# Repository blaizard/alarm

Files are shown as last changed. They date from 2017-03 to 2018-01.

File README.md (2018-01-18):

# Aube

Beautiful. Simple. Smart.

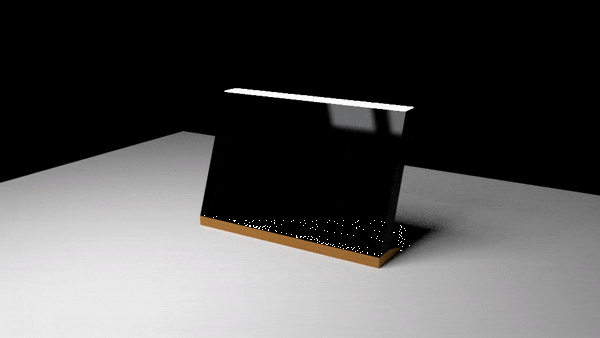
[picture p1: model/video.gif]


Aube is a smart alarm clock. It will guide you from the time you touch your bed until you wake up and is here make it a pleasant experience.
Aube is 3 major ideas: a design, a light and a smart device. 

## How to build Aube

The prototype is based on a Raspberry Pi 3 with the official 7 inches touch screen.
To fully build Aube, you will need a 3d printer, electronic circuit knowledges and some time!

The source contains various directories:
- **casing**: Contains the 3d models to be printed in order to build the skeleton of Aube
- **fw**: The firmware written in C to be compiled and loaded to a Microchip SAMD21 Microcontroller
- **schematics**: The electronics to handle the LED lighting with proximity sensor and the other sensors
- **sw**: The GUI of the alarm clock, written in Vanilla-Javascript and some back-end in Python

## Why Aube?
Pronounced /ob/, it is the translation of “dawn” in French. Dawn is a peaceful and relaxing experience which Aube is here to recreate every morning.

## Features
These are the raw features of Aube:
- Stereo speakers
- White LED light to simulate sunlight (with adjustable intensity and color temperature) with hovering dimming
- Connectivity: Wi-Fi, Bluetooth and USB ports (1xUSB type-C and 2x USB type-B) for charging only
- High sensitivity microphone for sleep monitoring
- Temperature, humidity and pressure sensors
- Proximity sensor to light up the screen on proximate movements

## Design
Inspired by Nordic designs, Aube is simple, pure with straight lines and strong contrasts.
Additionally, the user can customize the design by selecting the wooden base material.

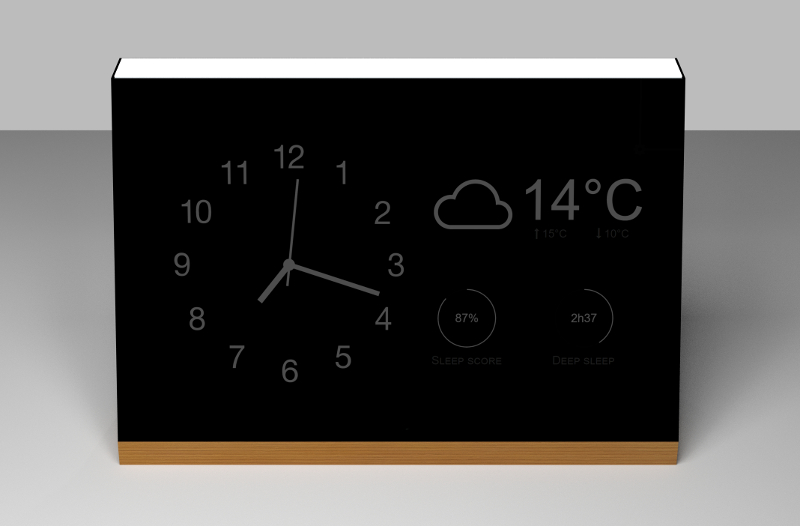
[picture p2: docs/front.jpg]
Front view


3D modelization of the casing of Aube, this contains all the necessary electronics.

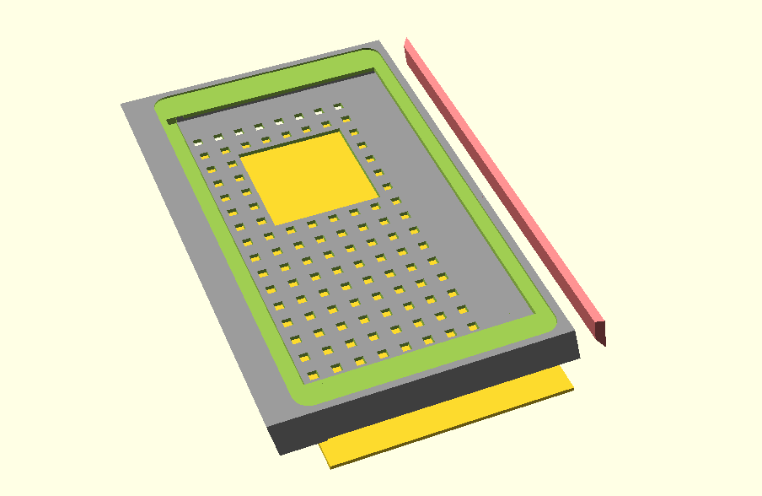
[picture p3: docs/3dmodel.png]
3d model


## Light
Our well-being and mood throughout the day is largely influenced by the light we are exposed to. Aube incorporates a light made to mimic the natural sun light.
Both intensity and light temperature can vary from 6500K to 4500K to recreate at best the color temperature of the light. Fade in from 4500K to 6500K in the morning to wake up smoothly and staying at 5000K in the evening to read a book before switching off the light.

The light has capacitive hovering capability, which means, without touching the device and by simply passing your hand on top of Aube, one can dim in or out the light.

Extract of the LED lighting circuitry.

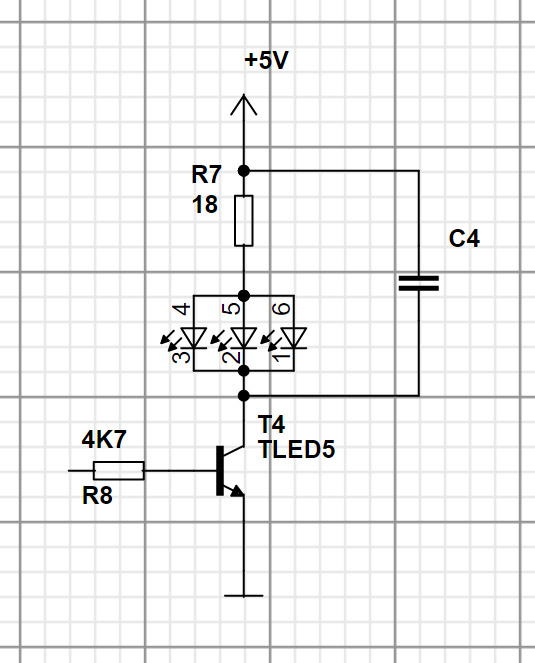
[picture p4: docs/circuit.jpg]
LED lighting


## Apps
A set of Apps are displayed on the main screen of the alarm clock to provide the user with a personalized dashboard. The layout and the Apps can be selected by the user and configured to fit customized needs.

The following describes the default Apps coming with Aube. They all come with various designs that can be selected to create a personalized experience.

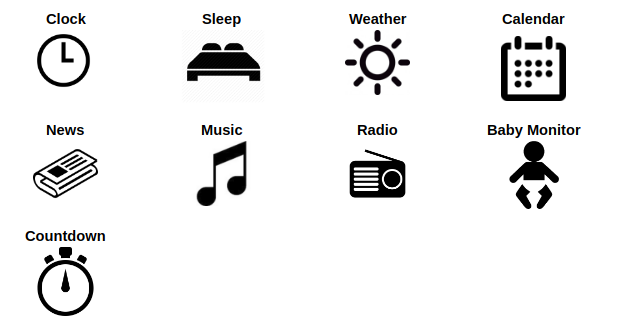
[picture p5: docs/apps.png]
Applications


## Clock
The clock is the essential application for an alarm clock. It’s core functionality is to provide accurate time but also notify the user on important times or dates.

Alarms can trigger an action or a chain of actions, for example, it can be configured to slowly dimm in the LED lights and play a music through Spotify. Or open the blind and start your coffee machine… anything combination of operation is possible and configurable.

Actions can be:
- Dimm in/out the embedded LED light
- Speak out a predefined message
- Trigger actions from any Apps available (Spotify with the Music Apps, Meeting in the morning with the Calendar Apps…)
- IFTTT support to trigger up to 500+ services

## Sleep
Monitor your sleep using the integrated high sensitivity microphone. Can connect to sleep monitor devices for more accurate results.

It will also record your sleep (if you like), and give you insights (if you woke up, moved or even snored) during your sleep.

## Weather
Give you up to date information of the local weather. It can also provide you with the right forecast for the day when combined with the alarm. Or simply configured to give you the next 5 days forecast for your next vacations trip.
In addition, the weather Apps connects to internal sensors to give you current and accurate information about the pressure, humidity, luminosity and temperature of the room.

## Calendar
Connected to your personal calendar, it will inform you about your next meetings in the morning, to make sure you never miss any of your appointments!

## News
Aube will inform you of the main news every morning or RSS feed you connect it too. I can also read you a digest of the news every morning as you wake up.

## Music
Connect it to your favorite music provider: Spotify, … and it will wake you up with your favorite playlist in the morning.

## Radio
The radio Apps can connect to any digital radio or podcasts through the web to give you the right information in the morning or before you go to bed.

## Baby Monitor
Check if your baby is sleeping well with the Baby Monitor. It connects to your third party wireless camera or baby monitor to give you the information you need to ensure your peace of mind before you fall asleep.

## Countdown
Cannot wait for your next vacation? Your birthday? or your old friend coming to town? The countdown Apps will inform you about the remaining days before an event happen.

# Phone charging
In addition, Aube comes with USB ports on the back made to charge your phone. Equipped with USB Type-B and the new USB Type-C port, you should not need any other piece of electronics on your night stand anymore.

# Open Source Framework
All Apps are built on a fixed but powerful API (Application Programming Interface). This enables anyone to interact with the core functionality of Aube and hence develop compatible applications. Opening Aube to developers brings unlimited possibilities.

The process is simple, one needs to download the SDK (Software Development Kit), and follow the tutorial to develop its own application.

The application development is extremely simple in order to give anyone the possibility to develop its own Apps. In addition, applications are developed in the most predominant programming language (Javascript) and hence can be coupled with a variety of existing modules to speed up development.

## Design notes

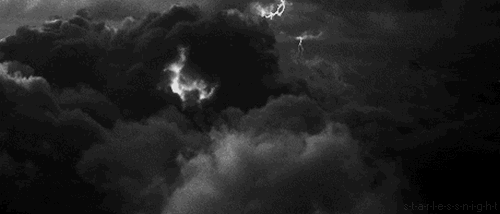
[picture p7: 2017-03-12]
sw/modules/weather/deps/imgs/storm.gif

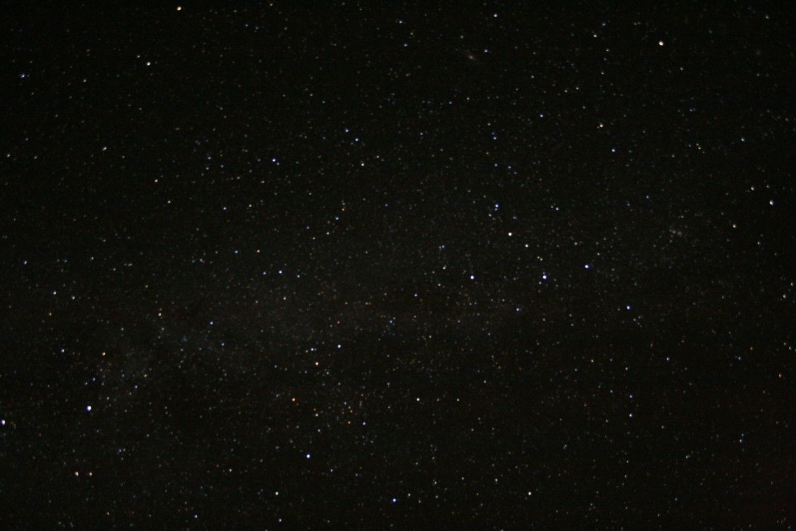
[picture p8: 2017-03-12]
sw/modules/weather/deps/imgs/night.jpg

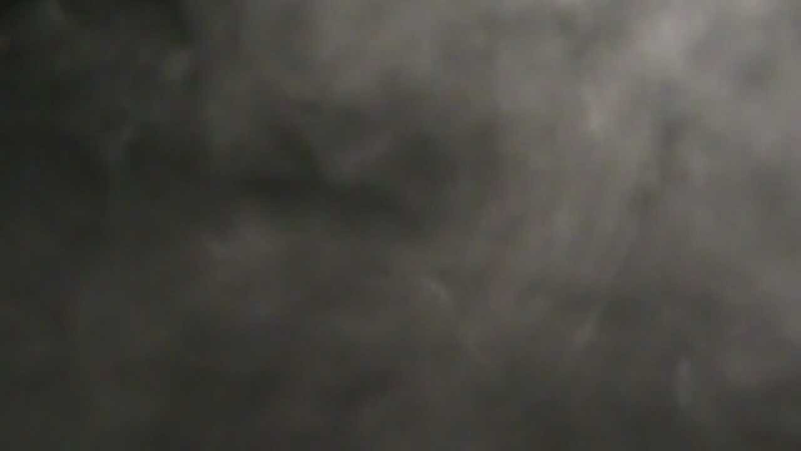
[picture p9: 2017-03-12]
sw/modules/weather/deps/imgs/fog.jpg

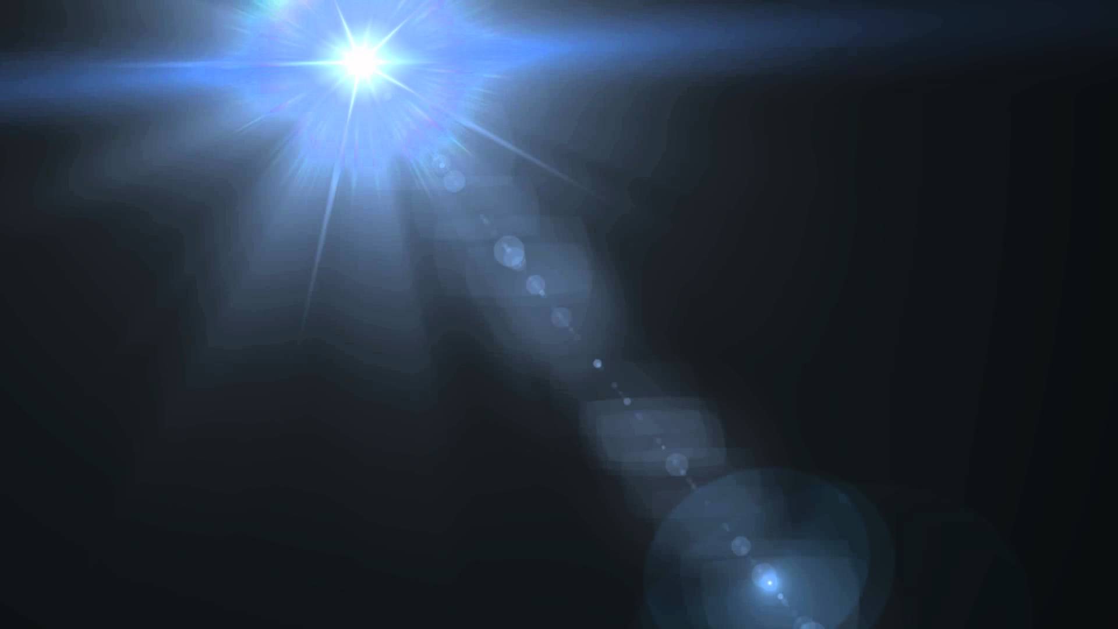
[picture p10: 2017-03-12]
sw/modules/weather/deps/imgs/sun.jpg

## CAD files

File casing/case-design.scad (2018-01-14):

// Higher definition curves
$fs = 0.1;

module createMeniscus(h,radius) // This module creates the shape that needs to be substracted from a cube to make its corners rounded.
difference(){        //This shape is basicly the difference between a quarter of cylinder and a cube
   translate([radius/2+0.1,radius/2+0.1,0]){
      cube([radius+0.2,radius+0.1,h+0.2],center=true);         // All that 0.x numbers are to avoid "ghost boundaries" when substracting
   }

   cylinder(h=h+0.2,r=radius,$fn = 25,center=true);
}


module roundCornersCube(x,y,z,r)  // Now we just substract the shape we have created in the four corners
difference(){
   cube([x,y,z], center=true);

    translate([x/2-r,y/2-r]){  // We move to the first corner (x,y)
      rotate(0){  
         createMeniscus(z,r); // And substract the meniscus
      }
   }
   translate([-x/2+r,y/2-r]){ // To the second corner (-x,y)
      rotate(90){
         createMeniscus(z,r); // But this time we have to rotate the meniscus 90 deg
      }
   }
      translate([-x/2+r,-y/2+r]){ // ... 
      rotate(180){
         createMeniscus(z,r);
      }
   }
      translate([x/2-r,-y/2+r]){
      rotate(270){
         createMeniscus(z,r);
      }
   }
}

usbWidth = 15;
module usb() {
    cube([7, 15, usbWidth], center = true);
}

module usbC() {
    cube([3, 10, 15], center = true);
}

powerWidth = 7;
module power() {
    cylinder(h=14, r=powerWidth/2, center=true);
}

module prism(l, w, h){
    polyhedron(
        points=[[0,0,0], [l,0,0], [l,w,0], [0,w,0], [0,w,h], [l,w,h]],
        faces=[[0,1,2,3],[5,4,3,2],[0,4,5,1],[0,3,4],[5,2,1]]
    );
}

height=125+4;
length=200;
width=20;
border=3;
shift=7.5;
screenYOffset = 3+2;

// Light shading
lsThickness = 3;

module createBox()
    color([0.6, 0.6, 0.6]) union() {
        difference() {
            cube([height, length, width], center = true);
            rotate([0, 0, 90])
                translate([-(length+1)/2, height/2-shift+0.1, -(width+1)/2])
                    prism(length+2, shift, width+1);
        }
        rotate([0, 0, 90])
            translate([-length/2, -height/2-shift, -width/2])
                prism(length, shift, width);
    };

module holes()
{
    holesBorder = 20;
    for (y=[-height/2+holesBorder+10:10:height/2-holesBorder])
        for (x=[-length/2+holesBorder:10:length/2-holesBorder])
            translate([y, x, -width/2+border/2])
                cube([4, 4, border+2], center=true);
    // Memory card access
  //  translate([5, 40, -width/2+border/2])
  //      cube([50, 50, border+2], center=true);
}
    

module lightShader(addToWidth, addToLength) {
    lsWidth = sqrt(width*width + shift*shift) + addToWidth;
    lsLength = length + addToLength;

    // Offset due to the inclination of the case
    lsAngle = atan(shift/width);   
    lsOffset = tan(lsAngle)*lsThickness;

    color([1, 0.5, 0.5])
        rotate([180, 0, 90])
            translate([-lsLength/2, -lsThickness, -lsWidth/2])
                union() {
                    polyhedron(
                        points = [
                            [border,  0,  border - lsOffset ],  //0 *
                            [lsLength - border,  0,  border - lsOffset],  //1 *
                            [lsLength,  lsThickness,  0 ],  //2
                            [0,  lsThickness,  0 ],  //3
                            [border,  0,  lsWidth - border - lsOffset ],  //4 *
                            [lsLength - border,  0,  lsWidth - border - lsOffset],  //5 *
                            [lsLength,  lsThickness,  lsWidth ],  //6
                            [0,  lsThickness,  lsWidth ]   //7
                        ],
                        faces = [
                            [0,1,2,3],  // bottom
                            [4,5,1,0],  // front
                            [7,6,5,4],  // top
                            [5,6,2,1],  // right
                            [6,7,3,2],  // back
                            [7,4,0,3]
                        ]
                    );
                };
};


module case() {
    difference() {
        // Main box
        createBox();

        // Holes
        holes();
        
        // Connectors
        union()
        {
            lsAngle=atan(shift/width);
            pcbHeight = 5-2;
            yPosition = -height/2 + shift + pcbHeight;

            // USB1
            translate([yPosition + 7/2, -25 -usbWidth/2+1-2, -width/2])
                rotate([0, -lsAngle, 0])
                    usb();
            // USB2
            translate([yPosition + 7/2, 25 + usbWidth/2-1, -width/2])
                rotate([0, -lsAngle, 0])
                    usb();
            
            // USB-C
            translate([yPosition + 7/2, -15 + usbWidth/2-1, -width/2])
                rotate([0, -lsAngle, 0])
                    usbC();
            
            // Power
            translate([yPosition + 7/2, 15, -width/2])
                rotate([0, -lsAngle, 0])
                    power();
        }
        
        // Holes for sensors
        union()
        {
            yPosition = -height/2 + 6;
            lsAngle=atan(shift/width);
            // Small hole
            translate([yPosition, 3, width/2])
                rotate([0, -lsAngle, 0])
                    cylinder(h=14, r=0.5, center=true);
            // Big hole
            translate([yPosition, -3, width/2])
                rotate([0, -lsAngle, 0])
                    cylinder(h=14, r=1.5, center=true);
            // Hole for PCB
            translate([-height/2, 0,0])
                cube([50, length - border*2 + 3, width - border*2 + 3], center=true);
        }
        
        // Audio case
        {
            translate([shift, 0, -width/2-0.01-1])
                audioCase(0.5);
        }
    }
};



module audioCase(expand) {
    audioCaseThickness = 2;
    connectorWidth = 100;
    connectorHeight = 20;
    connectorAngle = 45;

    module half()
        translate([-height+connectorHeight+height/2- expand, -length/2 - expand, 0])
            union()
            {
                cube([height - connectorHeight + expand*2, length/2+expand, audioCaseThickness]);
                w1 = (length-connectorWidth+expand*2)/2;
                w2 = w1 - connectorHeight/tan(connectorAngle);
             /*   polyhedron(
                    points = [
                        [0,  0,  0 ],  //0 *
                        [-connectorHeight,  0,  0],  //1 *
                        [-connectorHeight,  w2,  0 ],  //2
                        [0,  w1,  0 ],  //3
                        [0,  0,  1 ],  //0 *
                        [-connectorHeight,  0,  1],  //1 *
                        [-connectorHeight,  w2,  1 ],  //2
                        [0,  w1,  1 ],  //3
                    ],
                    faces = [
                        [0,1,2,3],  // bottom
                        [4,5,1,0],  // front
                        [7,6,5,4],  // top
                        [5,6,2,1],  // right
                        [6,7,3,2],  // back
                        [7,4,0,3]
                    ]
                );*/
            };

    union()
    {
        half();
        mirror([0,1,0])
            half();
    }
};


module base() {
    baseHeight = 10;
    baseTopWidth = sqrt(width*width+shift*shift);
    baseWidth = 60;
    baseLength = length;

    color([0.5, 1, 0.5])
        difference()
        {
                union() {
                    polyhedron(
                        points = [
                            [0,  0,  0],  //0 *
                            [baseLength,  0,  0],  //1 *
                            [baseLength,  baseHeight,  0 ],  //2
                            [0,  baseHeight,  0 ],  //3
                            [0,  0,  baseTopWidth],  //4 *
                            [baseLength,  0,  baseTopWidth],  //5 *
                            [baseLength,  baseHeight,  baseWidth],  //6
                            [0,  baseHeight,  baseWidth]   //7
                        ],
                        faces = [
                            [0,1,2,3],  // bottom
                            [4,5,1,0],  // front
                            [7,6,5,4],  // top
                            [5,6,2,1],  // right
                            [6,7,3,2],  // back
                            [7,4,0,3]
                        ]
                    );
                };
                translate([-1,-1,baseWidth-10])
                    rotate([20,0,0])
                        cube([baseLength * 2, baseHeight * 2, baseTopWidth]);
        };
};

//lightShader(-3, -2);

/*
union()
{
    case();
    difference()
    {
        case();
        maxSize = max(length, width) * 2;
        rotate([0, 180, 0])
            translate([-52.5, -maxSize/2, -maxSize/2])
                cube(maxSize,center=false);
    }
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

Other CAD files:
casing/case.backup.scad
casing/case.scad
model/model.blend

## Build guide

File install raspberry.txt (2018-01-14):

Follow:
https://blog.gordonturner.com/2017/07/22/raspberry-pi-full-screen-browser-raspbian-july-2017/

or this one (actually better as no need for LXDE)
https://rataks.com/blog/raspberry-pi-touchscreen-in-moode-with-chromium.html

----- setup wifi

----- change password to 1234
>sudo vim.tiny /etc/pam.d/common-password
change:
	password        [success=1 default=ignore]      pam_unix.so sha512 minlen=4
>passwd

----- install nmcli

>sudo apt-get install network-manager
>sudo vim.tiny /etc/NetworkManager/NetworkManager.conf
# edit
[ifupdown]
managed=true
# reboot and set the wifi SSID and password
>nmcli device wifi con "HAPPPY FAMILY" password "tobiothecat"

---- change background screen to black

+ install:
# The packages to run the alarm
sudo apt-get install php5-fpm php5 php5-cli php5-json

>sudo vim.tiny .config/lxsession/LXDE-pi/autostart
---------- This is the content of restart

# Start the server and wait a bit to make sure it is started before chromium
@nohup /home/pi/alarm/tools/deploy.sh &
#@sleep 5

# Normal website that does not need any exceptions
@/usr/bin/chromium-browser --incognito --start-maximized --touch-events=enabled --enable-pinch --kiosk --disable-touch-drag-drop --enable-touchview --disable-touch-drag-drop --app=http://localhost:8000 -- -nocursor
# Enable mixed http/https content, remember if invalid certs were allowed (ie self signed certs)
#@/usr/bin/chromium-browser --incognito --start-maximized --kiosk --allow-running-insecure-content --remember-cert-error-decisions http://gordonturner.com
@unclutter -display :0 -noevents -grab
@xset s off
@xset s noblank
@xset -dpms

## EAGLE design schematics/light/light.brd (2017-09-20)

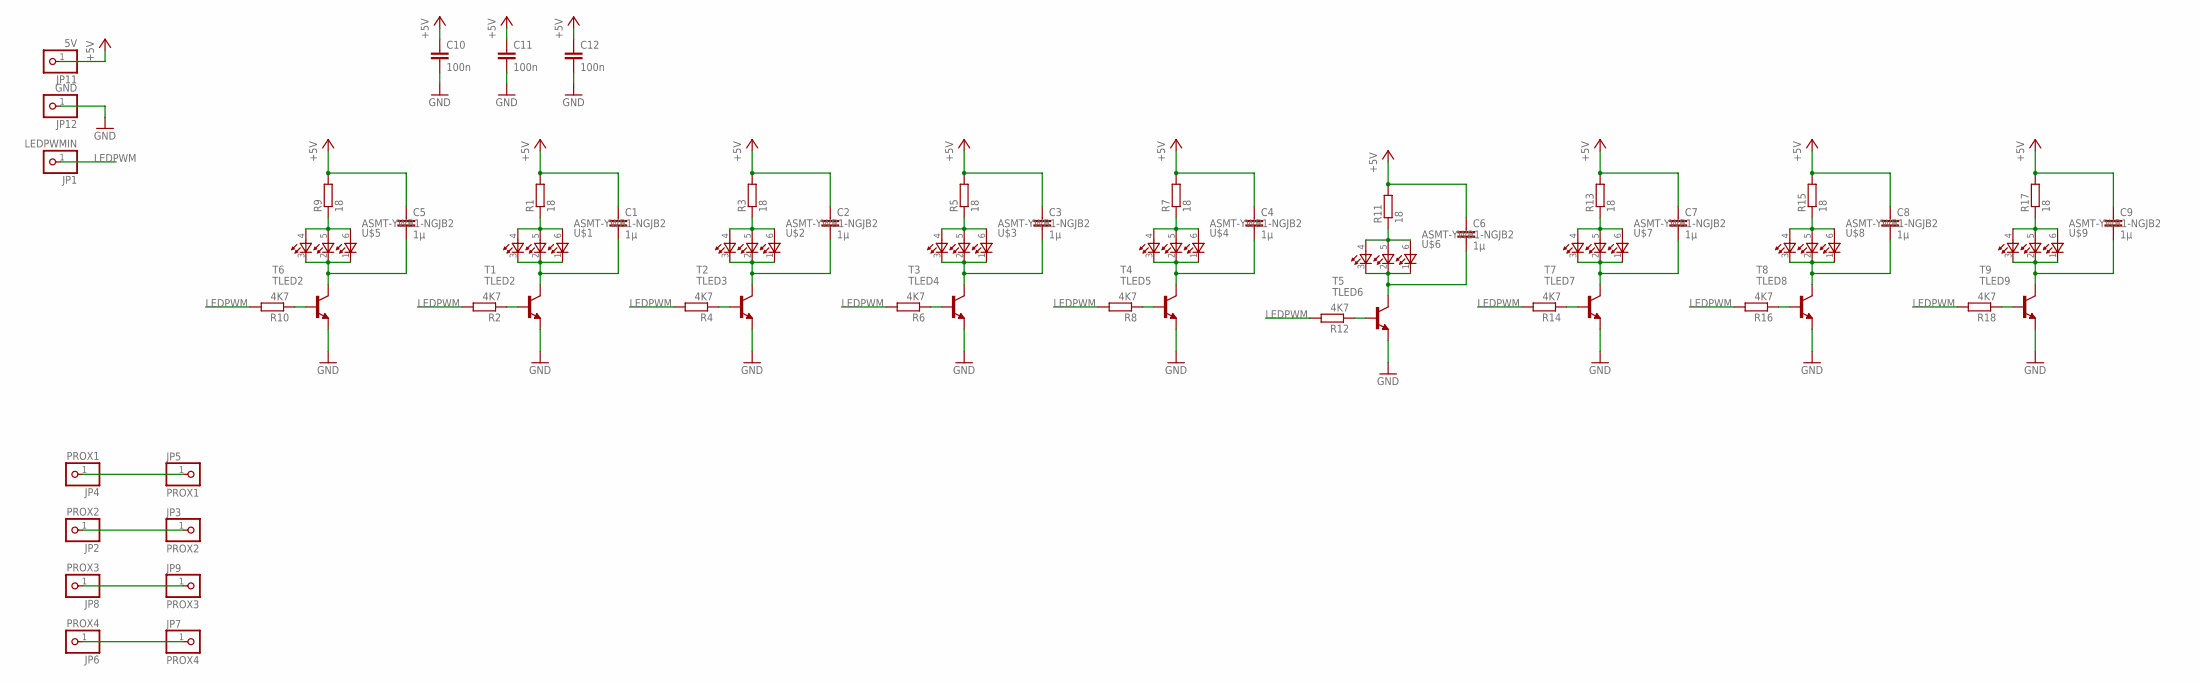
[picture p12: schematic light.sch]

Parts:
C1, C2, C3, C4, C5, C6, C7, C8, C9: 1µ; C0805
C10, C11, C12: 100n; C0805
JP1: LEDPWMIN; 1X01
JP2, JP3: PROX2; 1X01
JP4, JP5: PROX1; 1X01
JP6, JP7: PROX4; 1X01
JP8, JP9: PROX3; 1X01
JP11: 5V; 1X01
JP12: GND; 1X01
R1, R3, R5, R7, R9, R11, R13, R15, R17: 18; R0805
R2, R4, R6, R8, R10, R12, R14, R16, R18: 4K7; R0805
T1, T6: TLED2; SOT23-BEC
T2: TLED3; SOT23-BEC
T3: TLED4; SOT23-BEC
T4: TLED5; SOT23-BEC
T5: TLED6; SOT23-BEC
T7: TLED7; SOT23-BEC
T8: TLED8; SOT23-BEC
T9: TLED9; SOT23-BEC
U$1, U$2, U$3, U$4, U$5, U$6, U$7, U$8, U$9: ASMT-YWB1-NGJB2

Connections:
+5V: C1.1, C2.1, C3.1, C4.1, C5.1, C6.1, C7.1, C8.1, C9.1, C10.1, C11.1, C12.1, JP11.1, R1.2, R3.2, R5.2, R7.2, R9.2, R11.2, R13.2, R15.2, R17.2
BASE2: R12.1, T5.B
BASE3: R14.1, T7.B
BASE4: R16.1, T8.B
BASE5: R18.1, T9.B
COLLECTOR2: C6.2, T5.C, U$6.1, U$6.2, U$6.3
COLLECTOR3: C7.2, T7.C, U$7.1, U$7.2, U$7.3
COLLECTOR4: C8.2, T8.C, U$8.1, U$8.2, U$8.3
COLLECTOR5: C9.2, T9.C, U$9.1, U$9.2, U$9.3
GND: C10.2, C11.2, C12.2, JP12.1, T1.E, T2.E, T3.E, T4.E, T5.E, T6.E, T7.E, T8.E, T9.E
LEDPWM: JP1.1, R2.2, R4.2, R6.2, R8.2, R10.2, R12.2, R14.2, R16.2, R18.2
unnamed: R1.1, U$1.4, U$1.5, U$1.6
unnamed: C1.2, T1.C, U$1.1, U$1.2, U$1.3
unnamed: C2.2, T2.C, U$2.1, U$2.2, U$2.3
unnamed: R3.1, U$2.4, U$2.5, U$2.6
unnamed: R2.1, T1.B
unnamed: R4.1, T2.B
unnamed: C3.2, T3.C, U$3.1, U$3.2, U$3.3
unnamed: R5.1, U$3.4, U$3.5, U$3.6
unnamed: R6.1, T3.B
unnamed: C4.2, T4.C, U$4.1, U$4.2, U$4.3
unnamed: R7.1, U$4.4, U$4.5, U$4.6
unnamed: R8.1, T4.B
unnamed: R11.1, U$6.4, U$6.5, U$6.6
unnamed: C5.2, T6.C, U$5.1, U$5.2, U$5.3
unnamed: R13.1, U$7.4, U$7.5, U$7.6
unnamed: R15.1, U$8.4, U$8.5, U$8.6
unnamed: R17.1, U$9.4, U$9.5, U$9.6
unnamed: JP2.1, JP3.1
unnamed: JP4.1, JP5.1
unnamed: JP6.1, JP7.1
unnamed: JP8.1, JP9.1
unnamed: R9.1, U$5.4, U$5.5, U$5.6
unnamed: R10.1, T6.B

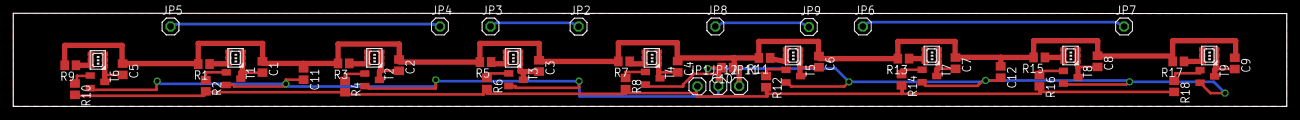
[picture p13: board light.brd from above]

Board: 2 copper layers, 192.0 x 14.0 mm, 59 parts (0 on the bottom side), 34 nets.

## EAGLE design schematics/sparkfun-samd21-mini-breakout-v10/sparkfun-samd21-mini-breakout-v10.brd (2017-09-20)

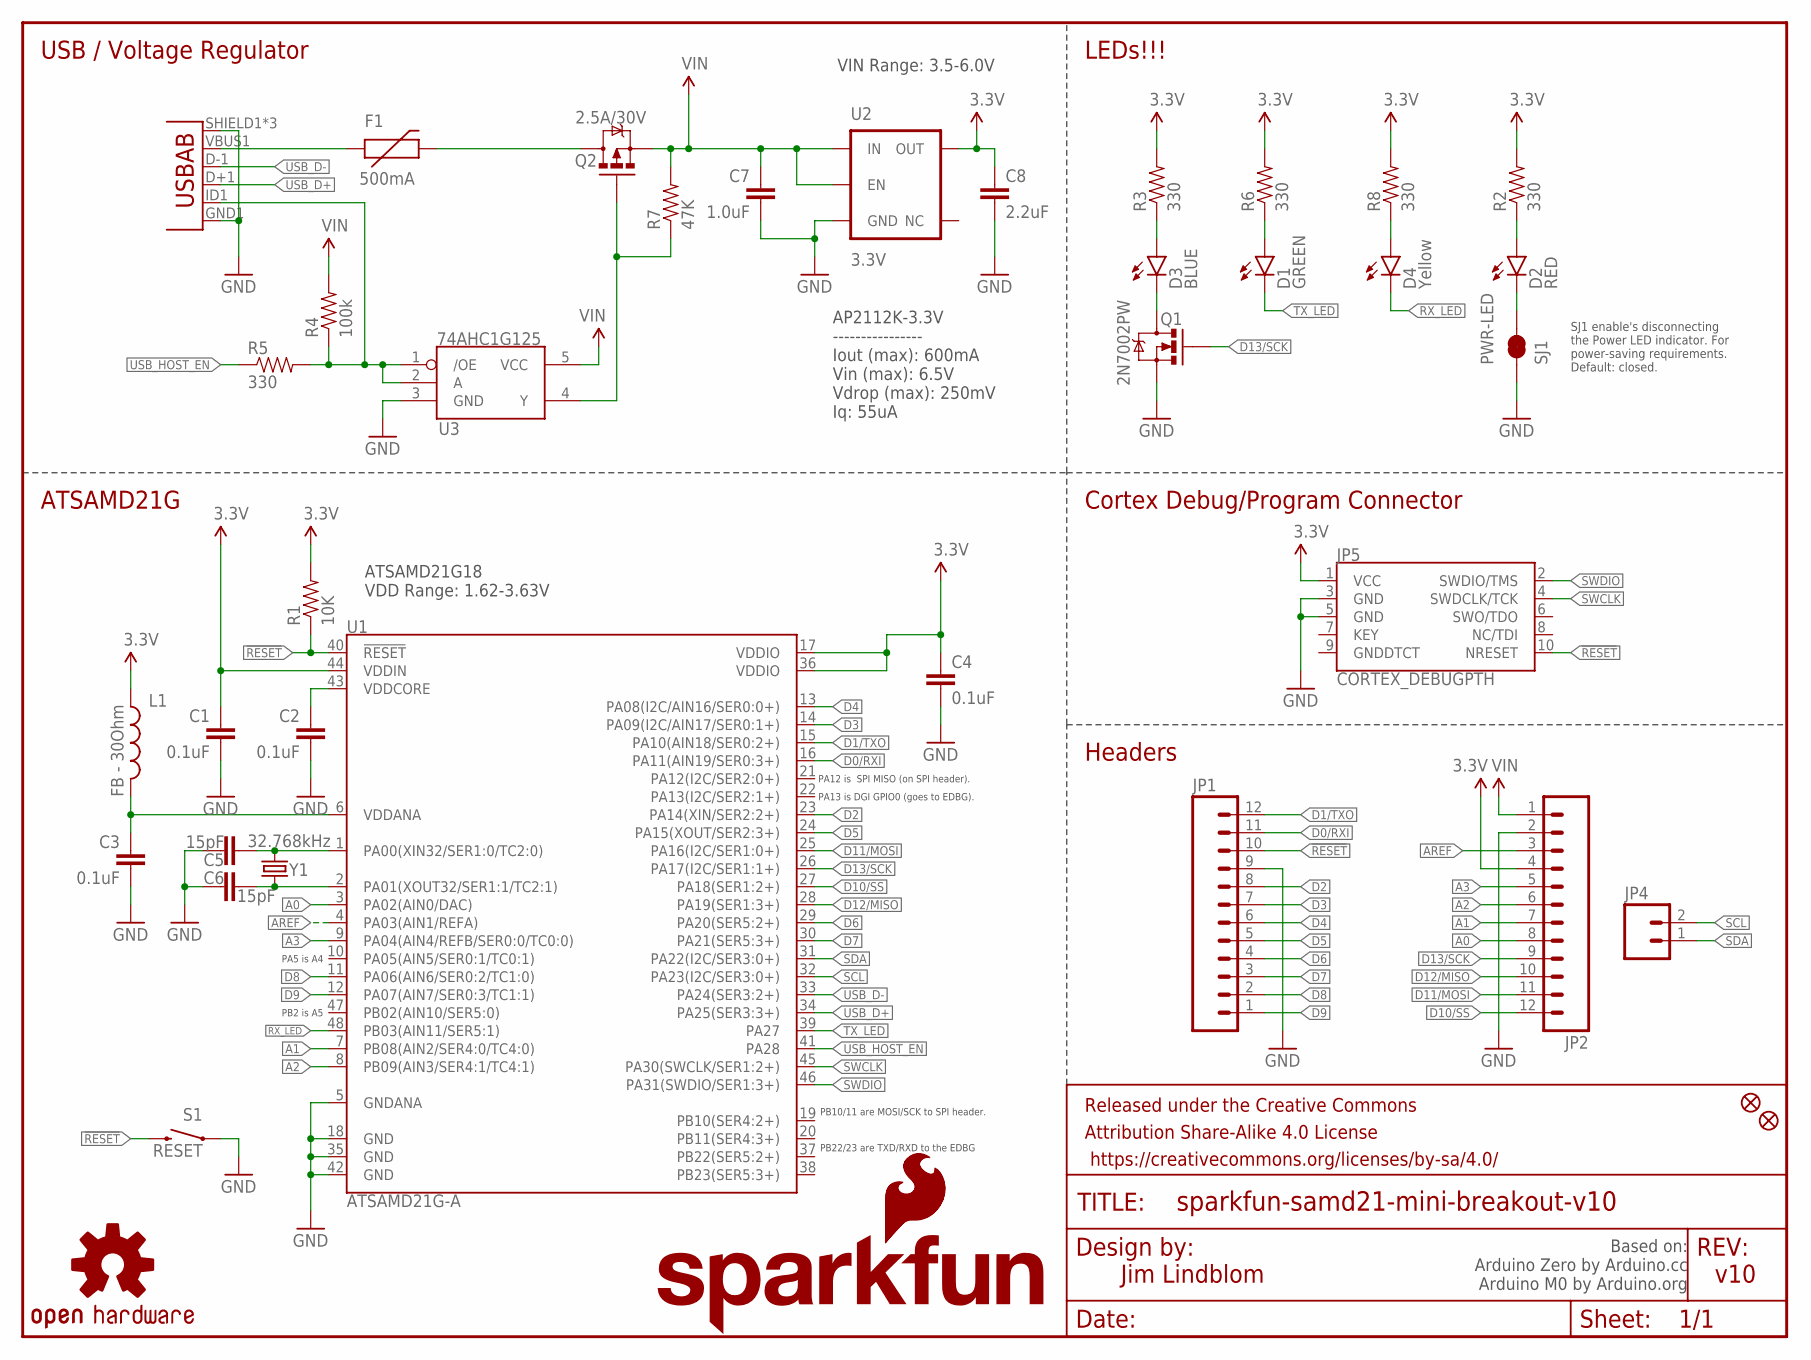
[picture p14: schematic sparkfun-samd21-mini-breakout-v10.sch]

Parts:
C1, C2, C3, C4: 0.1uF; 0402-CAP
C5, C6: 15pF; 0402-CAP
C7: 1.0uF; 0805-CAP
C8: 2.2uF; 0603-CAP
D1: GREEN; LED-0603
D2: RED; LED-0603
D3: BLUE; LED-0603
D4: Yellow; LED-0603
F1: 500mA; PTC-1206
FID1, FID2: FIDUCIAL1X2; FIDUCIAL-1X2
FRAME1: FRAME-LETTER; CREATIVE_COMMONS
JP1, JP2: M12NO_SILK; 1X12_NO_SILK
JP3: USB-ABCONN-11794; USB-AB-MICRO-SMD_V03
JP4: M021X02_NO_SILK; 1X02_NO_SILK
JP5: CORTEX_DEBUGPTH; 2X5-PTH-1.27MM
L1: FB - 30Ohm; 0603
LOGO1: SFE_LOGO_FLAME.1_INCH; SFE_LOGO_FLAME_.1
LOGO2: OSHW-LOGOS; OSHW-LOGO-S
LOGO3: SFE_LOGO_NAME_FLAME.1_INCH; SFE_LOGO_NAME_FLAME_.1
Q1: 2N7002PW; SOT323
Q2: 2.5A/30V; SOT23-3
R1: 10K; 0603-RES
R2, R3, R5, R6, R8: 330; 0603-RES
R4: 100k; 0603-RES
R7: 47K; 0603-RES
S1: RESET; TACTILE_SWITCH_SMD_4.6X2.8MM
SJ1: PWR-LED; PAD-JUMPER-2-NC_BY_TRACE_NO_SILK
U1: ATSAMD21G-A; TQFP-48
U2: 3.3V; SOT23-5
U3: 74AHC1G125; SOT23-5
Y1: 32.768kHz; CRYSTAL-SMD-3.2X1.5MM

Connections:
3.3V: C1.1, C4.1, C8.1, JP2.4, JP5.1 (VCC), L1.1, R1.2, R2.2, R3.2, R6.2, R8.2, U1.17 (VDDIO), U1.36 (VDDIO), U1.44 (VDDIN), U2.5 (OUT)
!RESET: JP1.10, JP5.10 (NRESET), R1.1, S1.3 (2), S1.4 (2), U1.40 (!RESET!)
A0: JP2.8, U1.3 (PA02(AIN0/DAC))
A1: JP2.7, U1.7 (PB08(AIN2/SER4:0/TC4:0))
A2: JP2.6, U1.8 (PB09(AIN3/SER4:1/TC4:1))
A3: JP2.5, U1.9 (PA04(AIN4/REFB/SER0:0/TC0:0))
AREF: JP2.3, U1.4 (PA03(AIN1/REFA))
D0/RXI: JP1.11, U1.16 (PA11(AIN19/SER0:3+))
D1/TXO: JP1.12, U1.15 (PA10(AIN18/SER0:2+))
D2: JP1.8, U1.23 (PA14(XIN/SER2:2+))
D3: JP1.7, U1.14 (PA09(I2C/AIN17/SER0:1+))
D4: JP1.6, U1.13 (PA08(I2C/AIN16/SER0:0+))
D5: JP1.5, U1.24 (PA15(XOUT/SER2:3+))
D6: JP1.4, U1.29 (PA20(SER5:2+))
D7: JP1.3, U1.30 (PA21(SER5:3+))
D8: JP1.2, U1.11 (PA06(AIN6/SER0:2/TC1:0))
D9: JP1.1, U1.12 (PA07(AIN7/SER0:3/TC1:1))
D10/SS: JP2.12, U1.27 (PA18(SER1:2+))
D11/MOSI: JP2.11, U1.25 (PA16(I2C/SER1:0+))
D12/MISO: JP2.10, U1.28 (PA19(SER1:3+))
D13/SCK: JP2.9, Q1.1 (G), U1.26 (PA17(I2C/SER1:1+))
GND: C1.2, C2.2, C3.2, C4.2, C5.1, C6.2, C7.2, C8.2, JP1.9, JP2.2, JP3.GND1 (GND), JP3.SHIELD1 (SHIELD), JP3.SHIELD2 (SHIELD), JP3.SHIELD3 (SHIELD), JP5.3 (GND), JP5.5 (GND), Q1.2 (S), S1.1, S1.2 (1), SJ1.1, U1.5 (GNDANA), U1.18 (GND), U1.35 (GND), U1.42 (GND), U2.2 (GND), U3.3 (GND)
unnamed: F1.1, JP3.VBUS1 (VBUS)
unnamed: C5.2, U1.1 (PA00(XIN32/SER1:0/TC2:0)), Y1.P$2 (2)
unnamed: D3.C, Q1.3 (D)
unnamed: C6.1, U1.2 (PA01(XOUT32/SER1:1/TC2:1)), Y1.P$1 (1)
unnamed: D2.A, R2.1
unnamed: D3.A, R3.1
unnamed: F1.2, Q2.3 (D)
unnamed: JP3.ID1 (USBID), R4.1, R5.2, U3.1 (/OE), U3.2 (A)
unnamed: Q2.1 (G), R7.1, U3.4 (Y)
unnamed: D1.A, R6.1
unnamed: D4.A, R8.1
unnamed: D2.C, SJ1.2
RX_LED: D4.C, U1.48 (PB03(AIN11/SER5:1))
SCL: JP4.2, U1.32 (PA23(I2C/SER3:0+))
SDA: JP4.1, U1.31 (PA22(I2C/SER3:0+))
SWCLK: JP5.4 (SWDCLK/TCK), U1.45 (PA30(SWCLK/SER1:2+))
SWDIO: JP5.2 (SWDIO/TMS), U1.46 (PA31(SWDIO/SER1:3+))
TX_LED: D1.C, U1.39 (PA27)
USB_D+: JP3.D+1 (D+), U1.34 (PA25(SER3:3+))
USB_D-: JP3.D-1 (D-), U1.33 (PA24(SER3:2+))
USB_HOST_EN: R5.1, U1.41 (PA28)
VDDANA: C3.1, L1.2, U1.6 (VDDANA)
VDDCORE: C2.1, U1.43 (VDDCORE)
VIN: C7.1, JP2.1, Q2.2 (S), R4.2, R7.2, U2.1 (IN), U2.3 (EN), U3.5 (VCC)

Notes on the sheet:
PB22/23 are TXD/RXD to the EDBG
PB10/11 are MOSI/SCK to SPI header.
PA12 is SPI MISO (on SPI header).
PA13 is DGI GPIO0 (goes to EDBG).
PA5 is A4
PB2 is A5
USB / Voltage Regulator
LEDs!!!
Cortex Debug/Program Connector
Headers
ATSAMD21G
Jim Lindblom
v10
ATSAMD21G18 VDD Range: 1.62-3.63V
SJ1 enable's disconnecting the Power LED indicator. For power-saving requirements. Default: closed.
VIN Range: 3.5-6.0V
Based on: Arduino Zero by Arduino.cc Arduino M0 by Arduino.org
AP2112K-3.3V ---------------- Iout (max): 600mA Vin (max): 6.5V Vdrop (max): 250mV Iq: 55uA

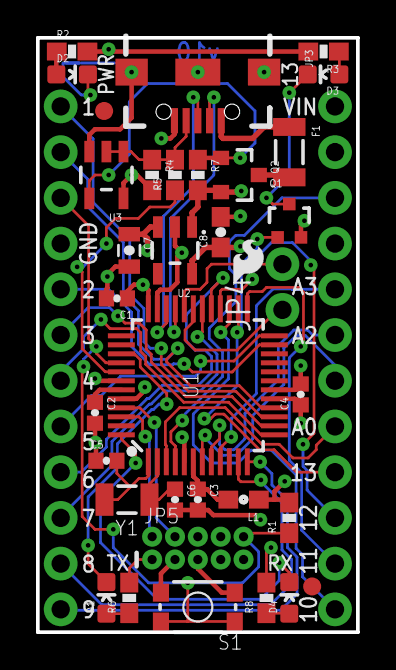
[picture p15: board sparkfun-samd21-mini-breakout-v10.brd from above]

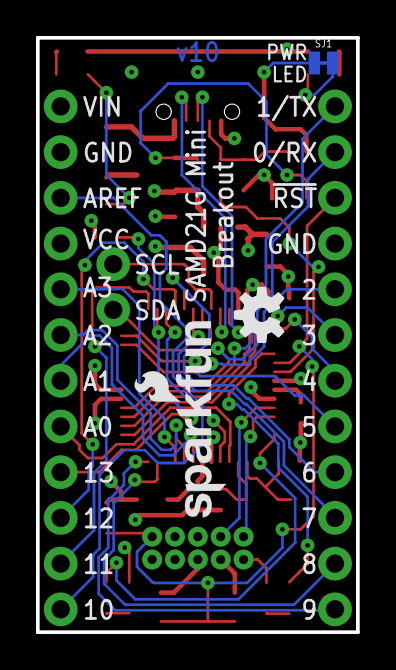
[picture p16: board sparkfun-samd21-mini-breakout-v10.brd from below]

Board: 4 copper layers, 17.8 x 33.0 mm, 41 parts (3 on the bottom side), 46 nets.

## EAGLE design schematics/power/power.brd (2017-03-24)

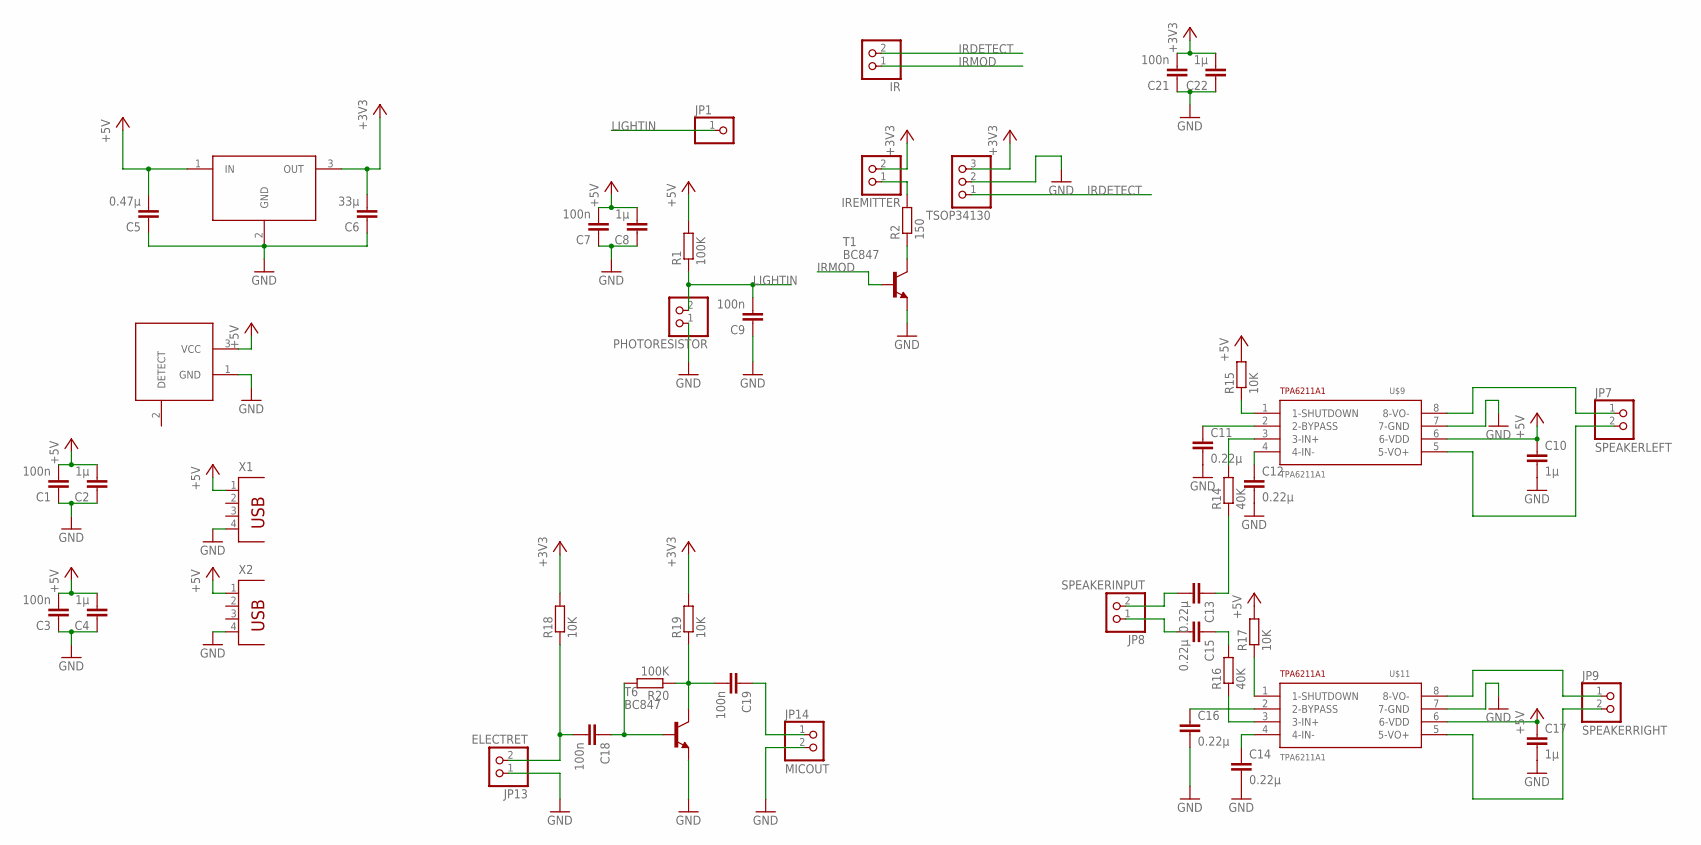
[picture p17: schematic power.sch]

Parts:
C1, C3, C7, C9, C18, C19, C21: 100n; C0805
C2, C4, C8, C10, C17, C22: 1µ; C0805
C5: 0.47µ; C0805
C6: 33µ; C0805
C11, C12, C13, C14, C15, C16: 0.22µ; C0805
IR: PINHD-1X2; 1X02
IREMITTER: PINHD-1X2; 1X02
JP1: PINHD-1X1; 1X01
JP7: SPEAKERLEFT; 1X02
JP8: SPEAKERINPUT; 1X02
JP9: SPEAKERRIGHT; 1X02
JP13: ELECTRET; 1X02
JP14: MICOUT; 1X02
PHOTORESISTOR: PINHD-1X2; 1X02
R1, R20: 100K; R0805
R2: 150; R0805
R14, R16: 40K; R0805
R15, R17, R18, R19: 10K; R0805
T1, T6: BC847; SOT23
TSOP34130: PINHD-1X3; 1X03
U$1: LM3940IMP-3.3; SOT223
U$2: POWERPLUG; DC10LPSOCKET
U$9, U$11: TPA6211A1; MSOP8
X1, X2: PN87520

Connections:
+3V3: C6.2, C21.2, C22.2, IREMITTER.2, R18.2, R19.2, TSOP34130.3, U$1.3 (OUT)
+5V: C1.2, C2.2, C3.2, C4.2, C5.2, C7.2, C8.2, C10.1, C17.1, R1.2, R15.2, R17.2, U$1.1 (IN), U$2.3 (VCC), U$9.6 (6-VDD), U$11.6 (6-VDD), X1.1, X2.1
GND: C1.1, C2.1, C3.1, C4.1, C5.1, C6.1, C7.1, C8.1, C9.1, C10.2, C11.2, C12.2, C14.2, C16.2, C17.2, C21.1, C22.1, JP13.1, JP14.2, PHOTORESISTOR.1, T1.2 (E), T6.2 (E), TSOP34130.2, U$1.2 (GND), U$2.1 (GND), U$9.7 (7-GND), U$11.7 (7-GND), X1.4, X2.4
IRDETECT: IR.2, TSOP34130.1
IRMOD: IR.1, T1.1 (B)
LIGHTIN: C9.2, JP1.1, PHOTORESISTOR.2, R1.1
unnamed: IREMITTER.1, R2.2
unnamed: R2.1, T1.3 (C)
unnamed: C13.1, R14.1
unnamed: C13.2, JP8.2
unnamed: JP7.1, U$9.8 (8-VO-)
unnamed: JP7.2, U$9.5 (5-VO+)
unnamed: C11.1, U$9.2 (2-BYPASS)
unnamed: C12.1, U$9.4 (4-IN-)
unnamed: R14.2, U$9.3 (3-IN+)
unnamed: C15.2, JP8.1
unnamed: C15.1, R16.2
unnamed: R15.1, U$9.1 (1-SHUTDOWN)
unnamed: R16.1, U$11.3 (3-IN+)
unnamed: C14.1, U$11.4 (4-IN-)
unnamed: C16.1, U$11.2 (2-BYPASS)
unnamed: R17.1, U$11.1 (1-SHUTDOWN)
unnamed: JP9.1, U$11.8 (8-VO-)
unnamed: JP9.2, U$11.5 (5-VO+)
unnamed: C19.2, R19.1, R20.1, T6.3 (C)
unnamed: C18.1, R20.2, T6.1 (B)
unnamed: C18.2, JP13.2, R18.1
unnamed: C19.1, JP14.1

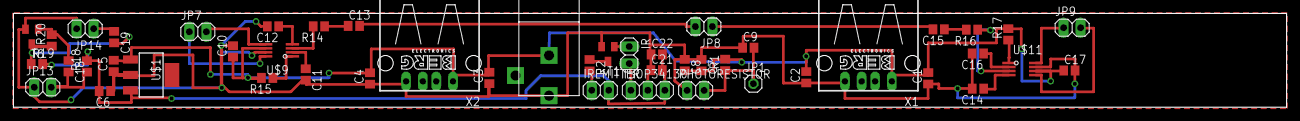
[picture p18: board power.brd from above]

Board: 2 copper layers, 190.0 x 14.0 mm, 48 parts (0 on the bottom side), 28 nets.

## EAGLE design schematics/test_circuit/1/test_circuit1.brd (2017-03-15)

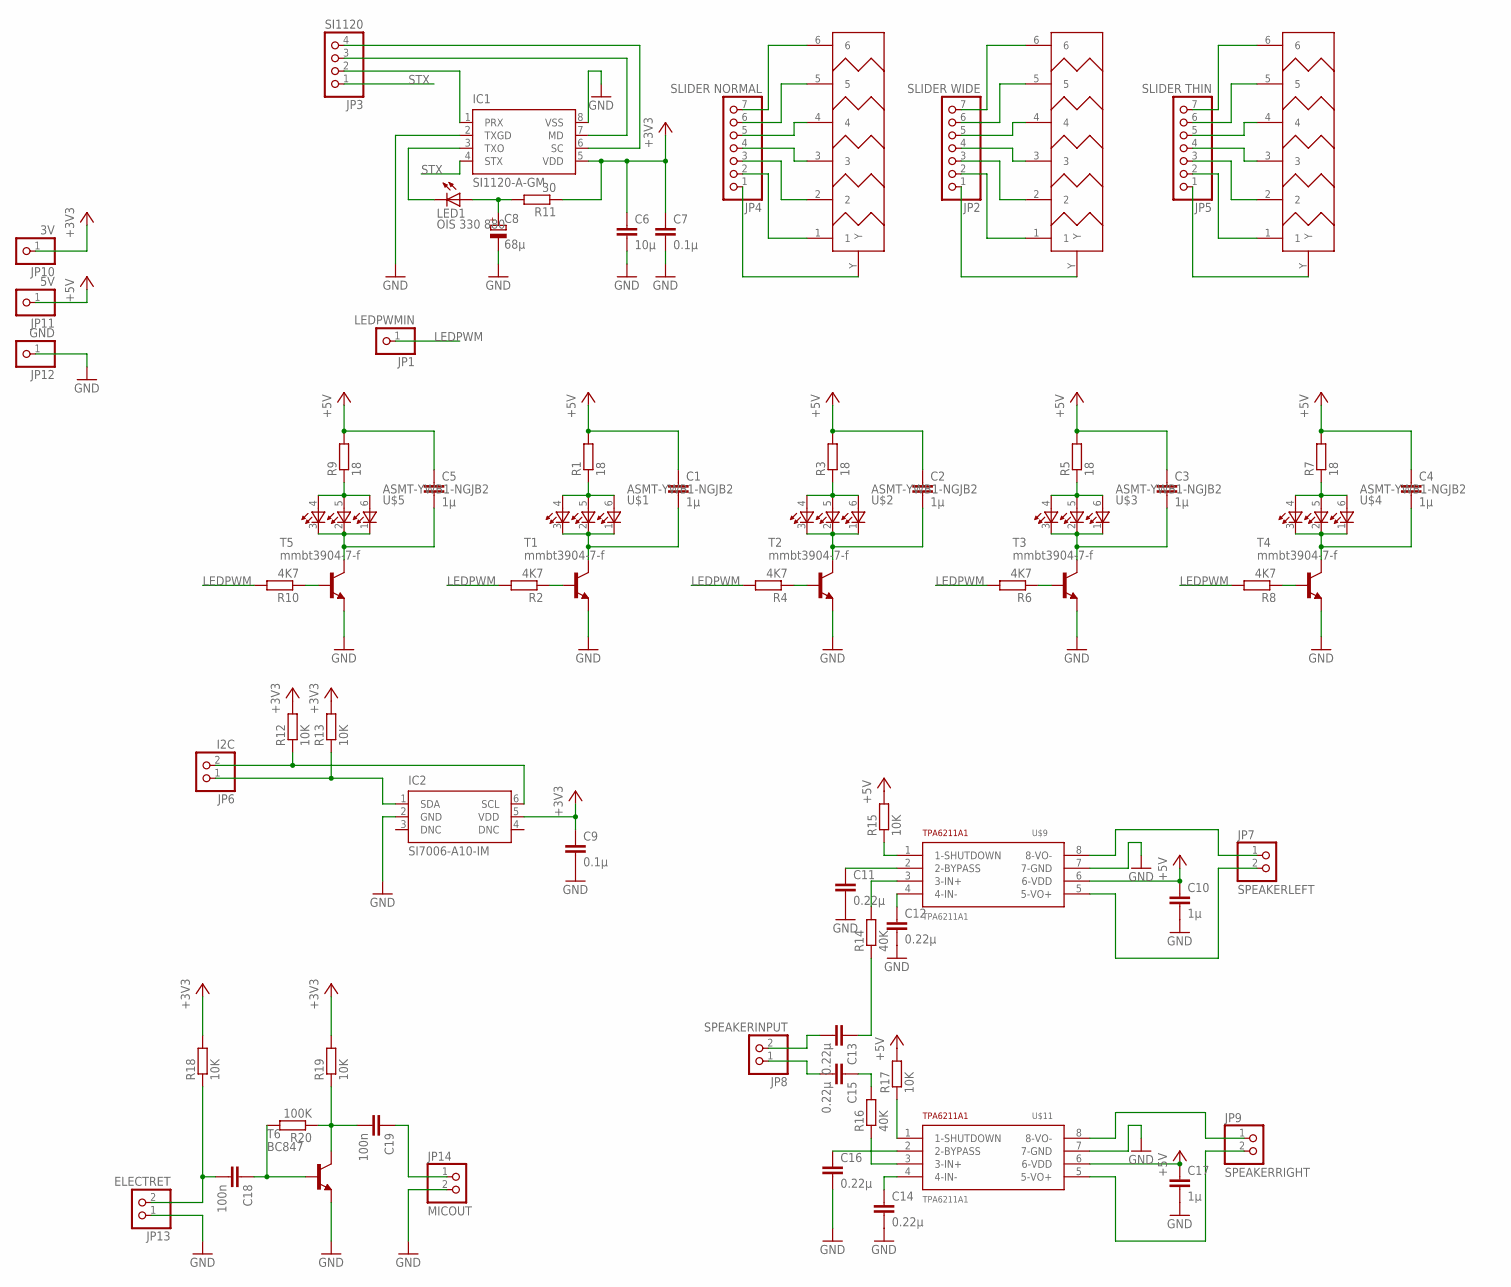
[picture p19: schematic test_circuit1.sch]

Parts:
C1, C2, C3, C4, C5, C10, C17: 1µ; C0805
C6: 10µ; C0805
C7, C9: 0.1µ; C0805
C8: 68µ; E2,5-7
C11, C12, C13, C14, C15, C16: 0.22µ; C0805
C18, C19: 100n; C0805
IC1: SI1120-A-GM; ODFN8-3X3
IC2: SI7006-A10-IM; DFN6-3X3
JP1: LEDPWMIN; 1X01
JP2: SLIDER WIDE; 1X07
JP3: SI1120; 1X04
JP4: SLIDER NORMAL; 1X07
JP5: SLIDER THIN; 1X07
JP6: I2C; 1X02
JP7: SPEAKERLEFT; 1X02
JP8: SPEAKERINPUT; 1X02
JP9: SPEAKERRIGHT; 1X02
JP10: 3V; 1X01
JP11: 5V; 1X01
JP12: GND; 1X01
JP13: ELECTRET; 1X02
JP14: MICOUT; 1X02
LED1: OIS 330 880; SML1206
R1, R3, R5, R7, R9: 18; R0805
R2, R4, R6, R8, R10: 4K7; R0805
R11: 30; R0805
R12, R13, R15, R17, R18, R19: 10K; R0805
R14, R16: 40K; R0805
R20: 100K; R0805
T1, T2, T3, T4, T5: mmbt3904-7-f; SOT23-EBC
T6: BC847; SOT23
U$1, U$2, U$3, U$4, U$5: ASMT-YWB1-NGJB2
U$6: SLIDER160MM_RESINT; SLIDER160MM_RI
U$7: SLIDER16MM_RESINT_WIDEY; SLIDER160MM_RI_WIDERY
U$8: SLIDER160MM_RESINT_THIN; SLIDER160MM_RI_THIN
U$9, U$11: TPA6211A1; MSOP8

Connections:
+3V3: C6.1, C7.1, C9.1, IC1.5 (VDD), IC2.5 (VDD), JP10.1, R11.1, R12.2, R13.2, R18.2, R19.2
+5V: C1.1, C2.1, C3.1, C4.1, C5.1, C10.1, C17.1, JP11.1, R1.2, R3.2, R5.2, R7.2, R9.2, R15.2, R17.2, U$9.6 (6-VDD), U$11.6 (6-VDD)
GND: C6.2, C7.2, C8.-, C9.2, C10.2, C11.2, C12.2, C14.2, C16.2, C17.2, IC1.2 (TXGD), IC1.8 (VSS), IC2.2 (GND), JP12.1, JP13.1, JP14.2, T1.E, T2.E, T3.E, T4.E, T5.E, T6.2 (E), U$9.7 (7-GND), U$11.7 (7-GND)
LEDPWM: JP1.1, R2.2, R4.2, R6.2, R8.2, R10.2
unnamed: R1.1, U$1.4, U$1.5, U$1.6
unnamed: C1.2, T1.C, U$1.1, U$1.2, U$1.3
unnamed: C2.2, T2.C, U$2.1, U$2.2, U$2.3
unnamed: R3.1, U$2.4, U$2.5, U$2.6
unnamed: R2.1, T1.B
unnamed: R4.1, T2.B
unnamed: C3.2, T3.C, U$3.1, U$3.2, U$3.3
unnamed: R5.1, U$3.4, U$3.5, U$3.6
unnamed: R6.1, T3.B
unnamed: C4.2, T4.C, U$4.1, U$4.2, U$4.3
unnamed: R7.1, U$4.4, U$4.5, U$4.6
unnamed: R8.1, T4.B
unnamed: C5.2, T5.C, U$5.1, U$5.2, U$5.3
unnamed: R9.1, U$5.4, U$5.5, U$5.6
unnamed: R10.1, T5.B
unnamed: JP4.7, U$6.6
unnamed: JP4.6, U$6.5
unnamed: JP4.5, U$6.4
unnamed: JP4.4, U$6.3
unnamed: JP4.3, U$6.2
unnamed: JP4.2, U$6.1
unnamed: IC1.3 (TXO), LED1.C
unnamed: C8.+, LED1.A, R11.2
unnamed: IC1.7 (MD), JP3.3
unnamed: IC1.6 (SC), JP3.4
unnamed: IC1.1 (PRX), JP3.2
unnamed: JP4.1, U$6.Y
unnamed: JP2.7, U$7.6
unnamed: JP2.6, U$7.5
unnamed: JP2.5, U$7.4
unnamed: JP2.4, U$7.3
unnamed: JP2.3, U$7.2
unnamed: JP2.2, U$7.1
unnamed: JP2.1, U$7.Y
unnamed: JP5.7, U$8.6
unnamed: JP5.6, U$8.5
unnamed: JP5.5, U$8.4
unnamed: JP5.4, U$8.3
unnamed: JP5.3, U$8.2
unnamed: JP5.2, U$8.1
unnamed: JP5.1, U$8.Y
unnamed: C13.1, R14.1
unnamed: C13.2, JP8.2
unnamed: IC2.6 (SCL), JP6.2, R12.1
unnamed: IC2.1 (SDA), JP6.1, R13.1
unnamed: JP7.1, U$9.8 (8-VO-)
unnamed: JP7.2, U$9.5 (5-VO+)
unnamed: C11.1, U$9.2 (2-BYPASS)
unnamed: C12.1, U$9.4 (4-IN-)
unnamed: R14.2, U$9.3 (3-IN+)
unnamed: C15.2, JP8.1
unnamed: C15.1, R16.2
unnamed: R15.1, U$9.1 (1-SHUTDOWN)
unnamed: R16.1, U$11.3 (3-IN+)
unnamed: C14.1, U$11.4 (4-IN-)
unnamed: C16.1, U$11.2 (2-BYPASS)
unnamed: R17.1, U$11.1 (1-SHUTDOWN)
unnamed: JP9.1, U$11.8 (8-VO-)
unnamed: JP9.2, U$11.5 (5-VO+)
unnamed: C19.2, R19.1, R20.1, T6.3 (C)
unnamed: C18.1, R20.2, T6.1 (B)
unnamed: C18.2, JP13.2, R18.1
unnamed: C19.1, JP14.1
STX: IC1.4 (STX), JP3.1

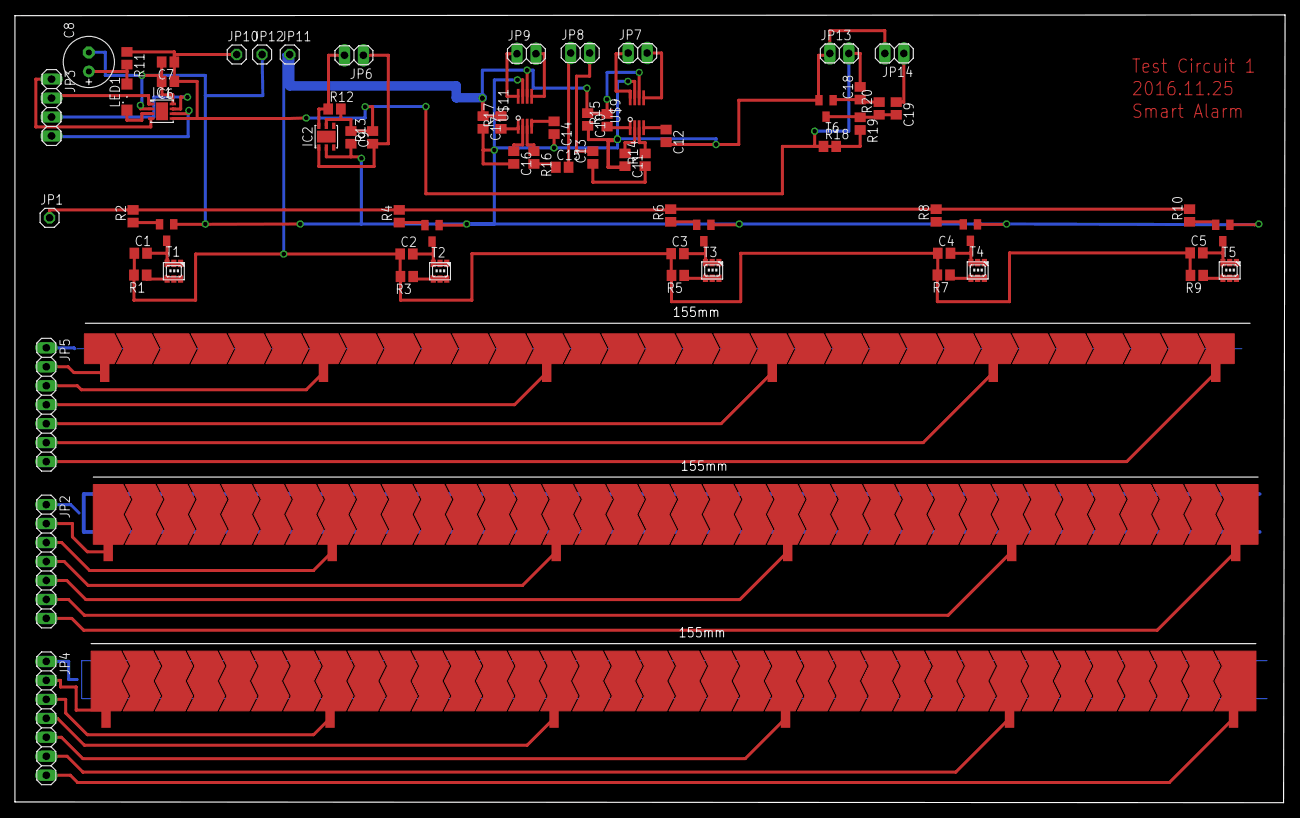
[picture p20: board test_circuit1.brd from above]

Board: 2 copper layers, 170.1 x 105.5 mm, 72 parts (0 on the bottom side), 68 nets.

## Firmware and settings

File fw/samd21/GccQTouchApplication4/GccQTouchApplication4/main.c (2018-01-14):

/* This source file is part of the ATMEL QTouch Library 5.0.7 */

/*****************************************************************************
 *
 * \file
 *
 * \brief  This file contains the SAMD QTouch library sample user application.
 *
 *
 * - Userguide:          QTouch Library Peripheral Touch Controller User Guide.
 * - Support email:      www.atmel.com/design-support/
 *
 *
 * Copyright (c) 2013-2015 Atmel Corporation. All rights reserved.
 *
 * \asf_license_start
 *
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
 * 3. The name of Atmel may not be used to endorse or promote products derived
 *    from this software without specific prior written permission.
 *
 * 4. This software may only be redistributed and used in connection with an
 *    Atmel microcontroller product.
 *
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
 * \asf_license_stop
 *
 ******************************************************************************/

/**
 * Include header files for all drivers that have been imported from
 * Atmel Software Framework (ASF).
 */
#include <asf.h>

/**
 * Device Revision definition
 */
#define DEVICE_REVISION_MASK (0xFu << 8)
#define DEVICE_REVISION_MASK_POS (8u)
#define DEV_REV_A (0x0)
#define DEV_REV_B (0x1)
#define DEV_REV_C (0x2)

struct rtc_module rtc_instance;
uint32_t device_rev = 0;

/*
 * switch_main_clock 
 */
void switch_main_clock(void);

/*! \brief Initialize timer
 *
 */
void timer_init( void );

/*! \brief RTC timer overflow callback
 *
 */
void rtc_overflow_callback(void);

/*! \brief Configure the RTC timer callback
 *
 */
void configure_rtc_callbacks(void);

/*! \brief Configure the RTC timer count after which interrupts comes
 *
 */
void configure_rtc_count(void);

/*! \brief Set timer period.Called from Qdebug when application
 *     has to change the touch time measurement
 */
void set_timer_period(void);

/*! \brief RTC timer overflow callback
 *
 */
void rtc_overflow_callback(void)
{
	/* Do something on RTC overflow here */
	touch_time.time_to_measure_touch = 1;
	touch_time.current_time_ms = touch_time.current_time_ms +
			touch_time.measurement_period_ms;
}

/*! \brief Configure the RTC timer callback
 *
 */
void configure_rtc_callbacks(void)
{
	/* register callback */
	rtc_count_register_callback(&rtc_instance,
			rtc_overflow_callback, RTC_COUNT_CALLBACK_OVERFLOW);
	/* Enable callback */
	rtc_count_enable_callback(&rtc_instance, RTC_COUNT_CALLBACK_OVERFLOW);
}

/*! \brief Configure the RTC timer count after which interrupts comes
 *
 */
void configure_rtc_count(void)
{
	struct rtc_count_config config_rtc_count;
	rtc_count_get_config_defaults(&config_rtc_count);
    #if ((SAMC20) || (SAMC21))
	config_rtc_count.prescaler           = RTC_MODE0_CTRLA_PRESCALER_DIV32;
    #else
	config_rtc_count.prescaler           = RTC_MODE0_CTRL_PRESCALER_DIV2;
    #endif
	config_rtc_count.mode                = RTC_COUNT_MODE_16BIT;
	#ifdef FEATURE_RTC_CONTINUOUSLY_UPDATED
	config_rtc_count.continuously_update = true;
	#endif
	/* initialize rtc */
	rtc_count_init(&rtc_instance, RTC, &config_rtc_count);

	/* enable rtc */
	rtc_count_enable(&rtc_instance);
}

/*! \brief Initialize timer
 *
 */
void timer_init(void)
{
	/* Configure and enable RTC */
	configure_rtc_count();

	/* Configure and enable callback */
	configure_rtc_callbacks();

	/* Set Timer Period */

	rtc_count_set_period(&rtc_instance, DEF_TOUCH_MEASUREMENT_PERIOD_MS);
}

/*! \brief Set timer period.Called from Qdebug when application
 *     has to change the touch time measurement
 */
void set_timer_period(void )
{
	rtc_count_set_period(&rtc_instance, touch_time.measurement_period_ms);
}

#if ((SAMC20) || (SAMC21))
void switch_main_clock(void)
{
	/* Update OSC48M Pre-scaler */
	struct system_clock_source_osc48m_config osc48m_config_ptr;
	
	system_clock_source_osc48m_get_config_defaults(&osc48m_config_ptr);
	
	osc48m_config_ptr.div = SYSTEM_OSC48M_DIV_1;
	osc48m_config_ptr.on_demand = false;
	osc48m_config_ptr.run_in_standby = true;
	system_clock_source_osc48m_set_config(&osc48m_config_ptr);
	
	struct system_gclk_gen_config gclk_conf;
	system_gclk_gen_get_config_defaults(&gclk_conf);
	gclk_conf.source_clock    = SYSTEM_CLOCK_SOURCE_OSC48M;
	gclk_conf.division_factor = 1;  //Pre-scaler
	gclk_conf.run_in_standby  = false;
	gclk_conf.output_enable   = false;
	system_gclk_gen_set_config(GCLK_GENERATOR_0, &gclk_conf);
	system_gclk_gen_enable(GCLK_GENERATOR_0);
	
	/* GCLK 1 - Main clock pre-scaled for PTC */
	system_gclk_gen_get_config_defaults(&gclk_conf);
	gclk_conf.source_clock    = SYSTEM_CLOCK_SOURCE_OSC48M;
	gclk_conf.division_factor = 12;  //Pre-scaler
	gclk_conf.run_in_standby  = true;
	gclk_conf.output_enable   = false;
	system_gclk_gen_set_config(GCLK_GENERATOR_1, &gclk_conf);
	system_gclk_gen_enable(GCLK_GENERATOR_1);
	
	/* Disable DPLL and corresponding GCLK */
	system_clock_source_disable(SYSTEM_CLOCK_SOURCE_DPLL);
	system_gclk_gen_disable(GCLK_GENERATOR_2);
	
	/* Set on demand bit of OSC48M to one */
	osc48m_config_ptr.on_demand = true;
	system_clock_source_osc48m_set_config(&osc48m_config_ptr);
}
#endif

void configure_tc(void);

struct tc_module tc_instance;

#define PWM_TC      TC3
#define PWM_PIN     PIN_PA18
#define PWM_PIN_MUX MUX_PA18E_TC3_WO0

void configure_tc(void)
{
	struct tc_config config_tc;
	tc_get_config_defaults(&config_tc);
	config_tc.counter_size = TC_COUNTER_SIZE_16BIT;
	config_tc.wave_generation = TC_WAVE_GENERATION_NORMAL_PWM;
	config_tc.pwm_channel[0].enabled = true;
	config_tc.pwm_channel[0].pin_out = PWM_PIN;
	config_tc.pwm_channel[0].pin_mux = PWM_PIN_MUX;
	tc_init(&tc_instance, PWM_TC, &config_tc);
	tc_set_compare_value(&tc_instance, TC_COMPARE_CAPTURE_CHANNEL_0, 0);
	tc_set_top_value(&tc_instance, 0xffff);
	tc_enable(&tc_instance);
}

void setDuty(const uint16_t targetDuty);
void setDuty(const uint16_t targetDuty)
{
	const uint16_t incDuty = 100;
	static uint16_t currentDuty = 0;

	if (currentDuty != targetDuty)
	{
		// Update the current duty
		currentDuty = (currentDuty > targetDuty) ? (currentDuty - incDuty) : (currentDuty + incDuty);
		currentDuty = (abs(currentDuty - targetDuty) < incDuty) ? targetDuty : currentDuty;

		// Convert duty to the next TC value
		// TC value = x^4
		uint32_t tcValue = ((uint32_t) currentDuty);
		tcValue = (((((tcValue * tcValue) >> 16) * tcValue) >> 16) * tcValue) >> 16;
		tcValue = (uint16_t) (tcValue);

		tc_set_compare_value(&tc_instance, TC_COMPARE_CAPTURE_CHANNEL_0, tcValue);
	}
}

#define GET_SELFCAP_SIGNAL(SENSOR_NUMBER) p_selfcap_measure_data->p_channel_signals[SENSOR_NUMBER]

/*! \brief Main function
 *
 */
int main(void)
{
	/**
	 * Initialize and configure system and generic clocks.
	 * Use conf_clocks.h to configure system and generic clocks.
	 * This example project uses Internal 8MHz oscillator.
	 * The PTC module clock is provided using GCLK generator 1.
	 */
	system_init();

    #if ((SAMC20) || (SAMC21))
	device_rev = ((DSU->DID.reg & DEVICE_REVISION_MASK) >> DEVICE_REVISION_MASK_POS);
	
	if(device_rev >= DEV_REV_C)
	{ 
	/* configure the cpu clock to OSC48MHz, and enable required GCLKs*/
		switch_main_clock();
	}
	#endif
	/**
	 * Initialize delay service.
	 */
	delay_init();

	/**
	 * Initialize timer.
	 * This example projects uses RTC timer for providing timing
	 * info to QTouch library.
	 */
	timer_init();

	/**
	 * Initialize QTouch library and configure touch sensors.
	 */
	touch_sensors_init();

	/* Configure System Sleep mode to standby MODE. */
      
   //	  system_set_sleepmode(SYSTEM_SLEEPMODE_STANDBY);
	  
    configure_tc();

	setDuty(0xffff);

	//DEF_TOUCH_MEASUREMENT_PERIOD_MS

	const size_t CALIBRATION_NB_SAMPLES = 256;
	const size_t offset = 20;
	uint16_t thresholds[DEF_SELFCAP_NUM_CHANNELS] = {0};
	uint32_t avgThresholds[DEF_SELFCAP_NUM_CHANNELS] = {0};
	size_t calibrationCounter = 0;
	uint16_t targetDuty = 0;

	while (1)
	{
		/**
		 * Goto STANDBY sleep mode, unless woken by timer or PTC
		 *interrupt.
		 */
		system_sleep();

		/**
		 * Start touch sensor measurement, if
		 *touch_time.time_to_measure_touch flag is set by timer.
		 */
		touch_sensors_measure();

		/**
		 * Update touch status once measurement complete flag is set.
		 */

		if ((p_selfcap_measure_data->measurement_done_touch == 1u))
		{
			const uint16_t signals[DEF_SELFCAP_NUM_CHANNELS] = {
				GET_SELFCAP_SIGNAL(0),
				GET_SELFCAP_SIGNAL(1),
				GET_SELFCAP_SIGNAL(2),
				GET_SELFCAP_SIGNAL(3)
			};

			// Update the calibration
			for (size_t i=0; i<DEF_SELFCAP_NUM_CHANNELS; ++i)
			{
				avgThresholds[i] += signals[i];
			}

			// Re-trigger a calibration
			if (calibrationCounter++ >= CALIBRATION_NB_SAMPLES)
			{
				for (size_t i=0; i<DEF_SELFCAP_NUM_CHANNELS; ++i)
				{
					thresholds[i] = avgThresholds[i] / CALIBRATION_NB_SAMPLES + offset;
					avgThresholds[i] = 0;
				}
				calibrationCounter = 0;
			}

			// Calculate the biggest difference'
			uint8_t position = -1;
			uint16_t positionDiff = 0;
			for (size_t i=0; i<DEF_SELFCAP_NUM_CHANNELS; ++i)
			{
				const uint16_t diff = (signals[i] < thresholds[i]) ? 0 : signals[i] - thresholds[i];
				if (diff)
				{
					if (positionDiff < diff)
					{
						position = i;
						positionDiff = diff;
					}
				}
			}

			switch (position)
			{
			case 0:
				targetDuty = 0xffff;
				break;
			case 1:
				targetDuty = 0xffff/3*2;
				break;
			case 2:
				targetDuty = 0xffff/3;
				break;
			case 3:
				targetDuty = 0;
				break;
			}

			setDuty(targetDuty);
		}
		   
		

		/**
		 * Self Cap method
		 * if ((p_selfcap_measure_data->measurement_done_touch == 1u))
		 * for self cap
		 * Touch sensor ON/OFF status or rotor/slider position.
		 *
		 * Self Cap method
		 * uint8_t sensor_state =
		 * GET_SELFCAP_SENSOR_STATE(SENSOR_NUMBER);
		 * uint8_t rotor_slider_position =
		 * GET_SELFCAP_ROTOR_SLIDER_POSITION(SENSOR_NUMBER);
		 *
		 */

		/**
		 * Mutual Cap method
		 * if ((p_mutlcap_measure_data->measurement_done_touch == 1u))
		 * for mutual cap
		 * Touch sensor ON/OFF status or rotor/slider position.
		 *
		 *
		 * uint8_t sensor_state =
		 * GET_MUTLCAP_SENSOR_STATE(SENSOR_NUMBER);
		 * uint8_t rotor_slider_position =
		 * GET_MUTLCAP_ROTOR_SLIDER_POSITION(SENSOR_NUMBER);
		 */
	}
}

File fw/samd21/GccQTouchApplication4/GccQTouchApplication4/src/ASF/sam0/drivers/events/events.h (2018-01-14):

/**
 * \file
 *
 * \brief SAM Event System Driver
 *
 * Copyright (C) 2012-2016 Atmel Corporation. All rights reserved.
 *
 * \asf_license_start
 *
 * \page License
 *
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
 * 3. The name of Atmel may not be used to endorse or promote products derived
 *    from this software without specific prior written permission.
 *
 * 4. This software may only be redistributed and used in connection with an
 *    Atmel microcontroller product.
 *
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
 * \asf_license_stop
 *
 */
/*
 * Support and FAQ: visit <a href="http://www.atmel.com/design-support/">Atmel Support</a>
 */
#ifndef EVENTS_H_INCLUDED
#define EVENTS_H_INCLUDED

#ifdef __cplusplus
extern "C" {
#endif

/**
 * \defgroup asfdoc_sam0_events_group SAM Event System (EVENTS) Driver
 *
 * This driver for Atmel&reg; | SMART ARM&reg;-based microcontrollers provides
 * an interface for the configuration and management of the device's peripheral
 * event resources and users within the device, including enabling and disabling
 * of peripheral source selection and synchronization of clock domains between
 * various modules. The following API modes is covered by this manual:
 *  - Polled API
 * \if EVENTS_INTERRUPT_HOOK_MODE
 *  - Interrupt hook API
 * \endif
 *
 * The following peripheral is used by this module:
 * - EVSYS (Event System Management)
 *
 * The following devices can use this module:
 *  - Atmel | SMART SAM D20/D21
 *  - Atmel | SMART SAM R21
 *  - Atmel | SMART SAM D09/D10/D11
 *  - Atmel | SMART SAM L21/L22
 *  - Atmel | SMART SAM DA1
 *  - Atmel | SMART SAM C20/C21
 *  - Atmel | SMART SAM R30
 *
 * The outline of this documentation is as follows:
 * - \ref asfdoc_sam0_events_prerequisites
 * - \ref asfdoc_sam0_events_module_overview
 * - \ref asfdoc_sam0_events_special_considerations
 * - \ref asfdoc_sam0_events_extra_info
 * - \ref asfdoc_sam0_events_examples
 * - \ref asfdoc_sam0_events_api_overview
 *
 *
 * \section asfdoc_sam0_events_prerequisites Prerequisites
 *
 * There are no prerequisites for this module.
 *
 *
 * \section asfdoc_sam0_events_module_overview Module Overview
 *
 * Peripherals within the SAM devices are capable of generating two types of
 * actions in response to given stimulus; set a register flag for later
 * intervention by the CPU (using interrupt or polling methods), or generate
 * event signals, which can be internally routed directly to other
 * peripherals within the device. The use of events allows for direct actions
 * to be performed in one peripheral in response to a stimulus in another
 * without CPU intervention. This can lower the overall power consumption of the
 * system if the CPU is able to remain in sleep modes for longer periods
 * (SleepWalking), and lowers the latency of the system response.
 *
 * The event system is comprised of a number of freely configurable Event
 * resources, plus a number of fixed Event Users. Each Event resource can be
 * configured to select the input peripheral that will generate the events
 * signal, as well as the synchronization path and edge detection mode.
 * The fixed-function Event Users, connected to peripherals within the device,
 * can then subscribe to an Event resource in a one-to-many relationship in order
 * to receive events as they are generated. An overview of the event system
 * chain is shown in
 * \ref asfdoc_sam0_events_module_overview_fig "the figure below".
 *
 * \anchor asfdoc_sam0_events_module_overview_fig
 * \dot
 * digraph overview {
 * rankdir=LR;
 * node [label="Source\nPeripheral\n(Generator)" shape=ellipse style=filled fillcolor=lightgray] src_peripheral;
 * node [label="Event\nResource A" shape=square style=""] event_gen0;
 * node [label="Event\nUser X" shape=square style=""] event_user0;
 * node [label="Event\nUser Y" shape=square style=""] event_user1;
 * node [label="Destination\nPeripheral\n(User)" shape=ellipse style=filled fillcolor=lightgray] dst_peripheral0;
 * node [label="Destination\nPeripheral\n(User)" shape=ellipse style=filled fillcolor=lightgray] dst_peripheral1;
 *
 * src_peripheral -> event_gen0;
 * event_gen0 -> event_user0;
 * event_gen0 -> event_user1;
 * event_user0 -> dst_peripheral0;
 * event_user1 -> dst_peripheral1;
 * }
 * \enddot
 *
 * There are many different events that can be routed in the device, which can
 * then trigger many different actions. For example, an Analog Comparator module
 * could be configured to generate an event when the input signal rises above
 * the compare threshold, which then triggers a Timer Counter module to capture
 * the current count value for later use.
 *
 * \subsection asfdoc_sam0_events_module_overview_event_channels Event Channels
 * The Event module in each device consists of several channels, which can be
 * freely linked to an event generator (i.e. a peripheral within the device
 * that is capable of generating events). Each channel can be individually
 * configured to select the generator peripheral, signal path, and edge detection
 * applied to the input event signal, before being passed to any event user(s).
 *
 * Event channels can support multiple users within the device in a standardized
 * manner. When an Event User is linked to an Event Channel, the channel will
 * automatically handshake with all attached users to ensure that all modules
 * correctly receive and acknowledge the event.
 *
 * \subsection asfdoc_sam0_events_module_overview_event_users Event Users
 * Event Users are able to subscribe to an Event Channel, once it has been
 * configured. Each Event User consists of a fixed connection to one of the
 * peripherals within the device (for example, an ADC module, or Timer module)
 * and is capable of being connected to a single Event Channel.
 *
 * \subsection asfdoc_sam0_events_module_overview_edge_detection Edge Detection
 * For asynchronous events, edge detection on the event input is not possible,
 * and the event signal must be passed directly between the event generator and
 * event user. For synchronous and re-synchronous events, the input signal from
 * the event generator must pass through an edge detection unit, so that only
 * the rising, falling, or both edges of the event signal triggers an action in
 * the event user.
 *
 * \subsection asfdoc_sam0_events_module_overview_path_selection Path Selection
 * The event system in the SAM devices supports three signal path types from
 * the event generator to Event Users: asynchronous, synchronous, and
 * re-synchronous events.
 *
 * \subsubsection asfdoc_sam0_events_module_overview_path_selection_async Asynchronous Paths
 * Asynchronous event paths allow for an asynchronous connection between the
 * event generator and Event Users, when the source and destination
 * peripherals share the same \ref asfdoc_sam0_system_clock_group "Generic Clock"
 * channel. In this mode the event is propagated between the source and
 * destination directly to reduce the event latency, thus no edge detection is
 * possible. The asynchronous event chain is shown in
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

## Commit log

2017-03-12 First version of the case
    [case.scad]
2017-03-15 Lighting board
    [light.brd, light.sch, test_circuit1.brd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]
2017-03-24 New update
    [case.scad, light.brd, power.brd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]
2017-09-20 Initial version
    [case.backup.scad, case.scad, light.brd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]
2018-01-14 Major update Y
    [audio.stl, base.stl, case-design.scad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]
2018-01-14 Removed useless stuffs Y
    [audio.stl, base.stl, case.stl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]
2018-01-17 Added some documentation
    [case.scad]

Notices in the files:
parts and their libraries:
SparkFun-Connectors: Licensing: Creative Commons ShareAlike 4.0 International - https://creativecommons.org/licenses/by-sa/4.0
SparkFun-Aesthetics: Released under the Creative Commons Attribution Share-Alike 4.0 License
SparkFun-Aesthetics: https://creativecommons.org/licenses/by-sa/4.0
